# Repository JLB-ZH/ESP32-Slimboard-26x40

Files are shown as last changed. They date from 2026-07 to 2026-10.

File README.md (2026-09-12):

# ESP32-Slimboard-26x40  
Compact ESP32‑WROOM‑32 slim board (26×40 mm) for vertical or horizontal mounting, with a 10‑pin ZIF for programming and I²C/SPI interface.

## 🧩 The Board
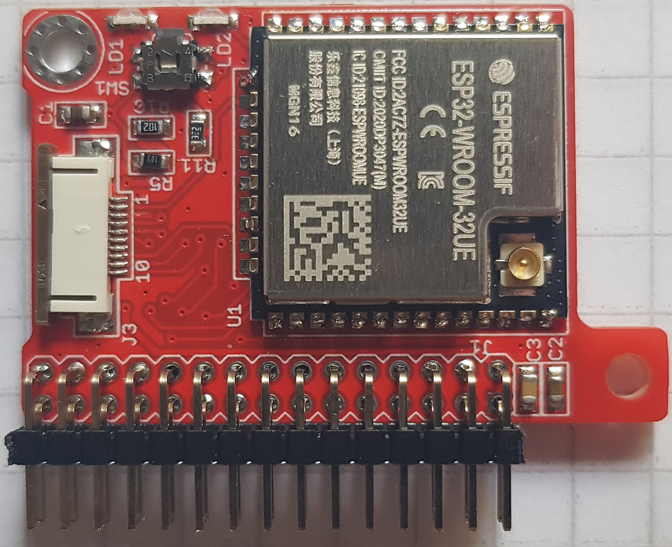
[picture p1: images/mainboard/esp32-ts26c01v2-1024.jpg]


The processor board is made arround the ESPRESSIF ESP32‑WROOM‑32UE with 16 MB of flash (or 32E if no external antenna needed).

USB interface and onboard 3.3V regulator are not provided, an external adapter (see [Tools](#-tools)) can be used for initial programming. OTA updates can be used afterwards.

The board features a 2×15 pin male connector with 2.0 mm pitch, allowing use on prototyping platforms or production boards.

It has been developed with Eagle Cad version 4.16, but Eagle 6 compatible files (XML format) are provided [here](hardware/), and can be easily imported into KICAD.

The mechanical and pinout specifications can apply to many different microcontroller or SOC, including BEKEN BK72xx series, REALTEK RTL8720, if no CANbus needed, just adapt the schematic and use the libraries available in JLB_processor.lbr.

## 📜 Specifications
- Small size: 26x40mm
- 2× holes for 2,5mm screews
- Soc module on-board: ESP32‑WROOM‑32‑E (or UE)
  - 240MHz
  - 16MB Flash
  - 520KB Sram
  - 448 KB Rom
  - CAN 2.0
  - Wifi, Bluetooth
  - many GPIOs
- Externally provided 3.3V power supply
- 1× 2×15×2.0 mm male connector
  - Straight version for horizontal mounting
  - Right‑angle version for vertical mounting  
- Reset button    
- 2× indicators
  - red LED on GPIO0  
  - green LED on GPIO2  
- 1× 1x10x0.5mm ZIF connector 
  - for Jtag or Uart programming (ESPPROG2 + adapter recommended)
  - for I²C or SPI expansion
## 🔌 Connectivity
### main connector
Pins in this table have been assigned to application-specific signals, but all GPIO can be reassigned to other functions by software if necessary.
Main connector
### Zif connector
Zif connector
## 🖼 Application examples and projects
<table>
  <tr>
    <td><strong>Linky interface</strong></td>
    <td><strong>Tank level Sensor interface</strong></td>
    <td><strong>Prototyping baseboard</strong></td>
  </tr>
  <tr>
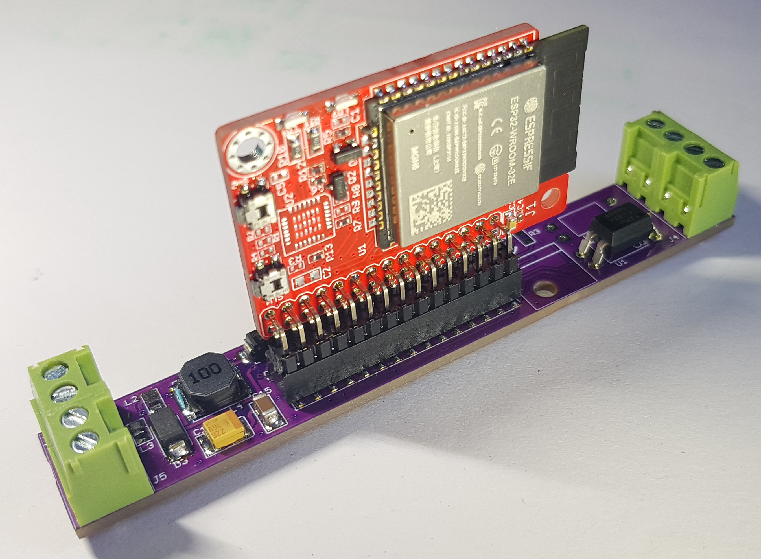
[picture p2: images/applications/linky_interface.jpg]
    <td></td>
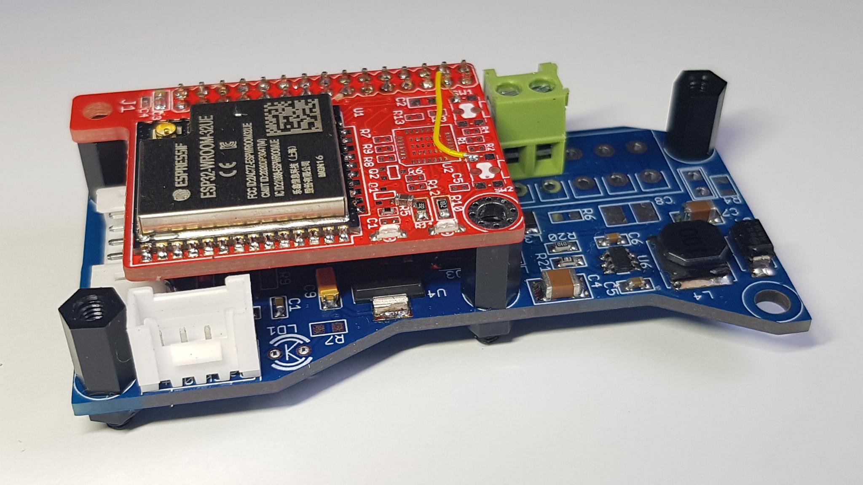
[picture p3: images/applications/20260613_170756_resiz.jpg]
    <td></td>
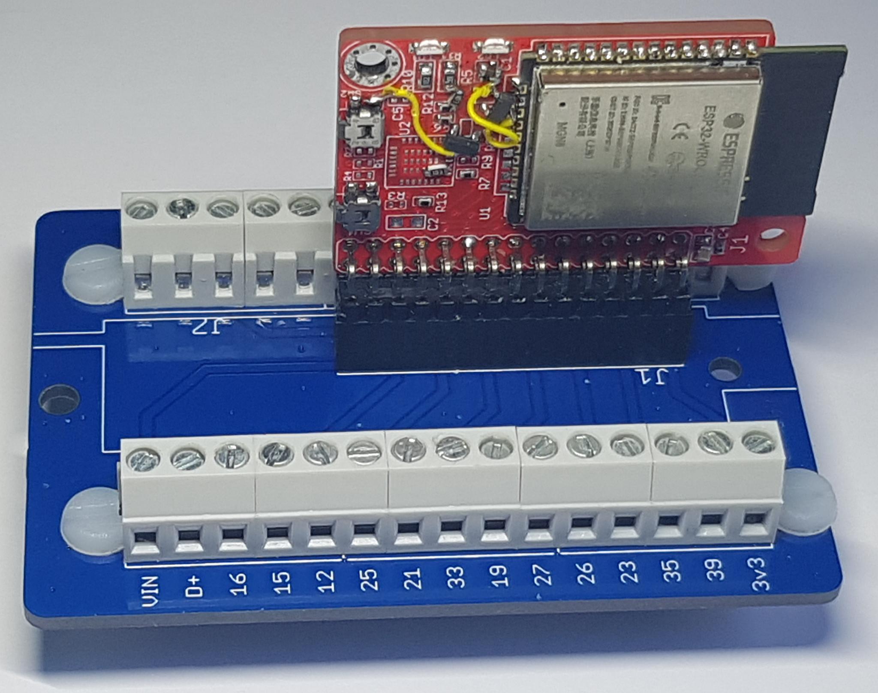
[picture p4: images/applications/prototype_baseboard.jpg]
    <td></td>
  </tr>
</table>

## 📐 Hardware design
Design and library files are provided [here](hardware/) in Eagle 6 format (xml files) that can easily be imported into KICAD.

## 🛠 Tools
|[Uart programming module](https://soldered.com/products/connect-programmer)|[ESPPROG-2 tool](https://docs.espressif.com/projects/esp-dev-kits/en/latest/other/esp-prog-2/user_guide.html)|ZIF programmer|Programming on socket|
|:---:|:---:|:---:|:---:|
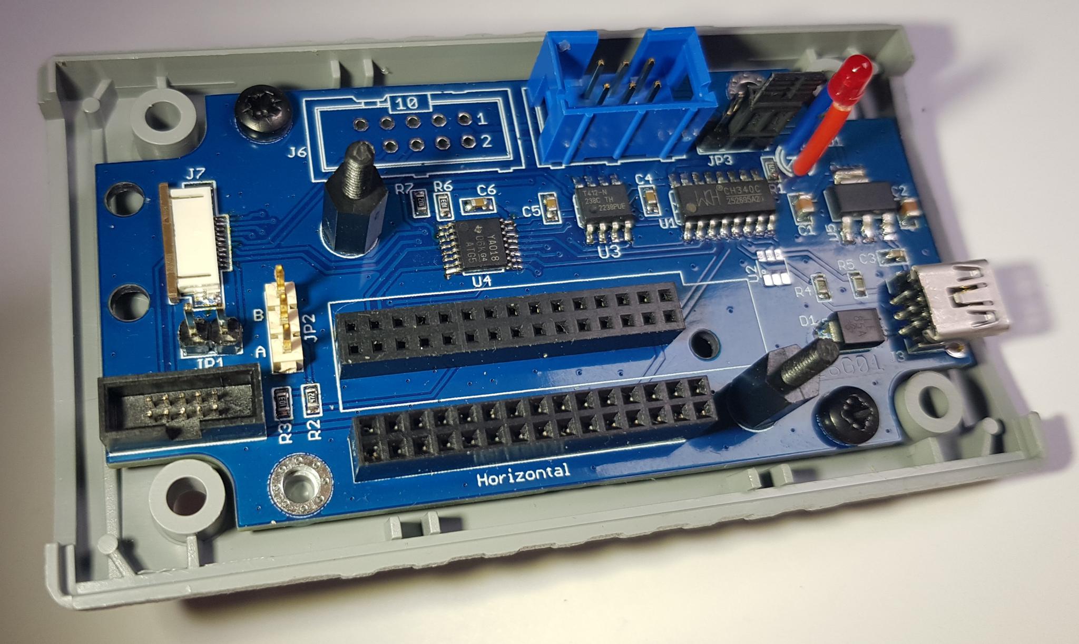
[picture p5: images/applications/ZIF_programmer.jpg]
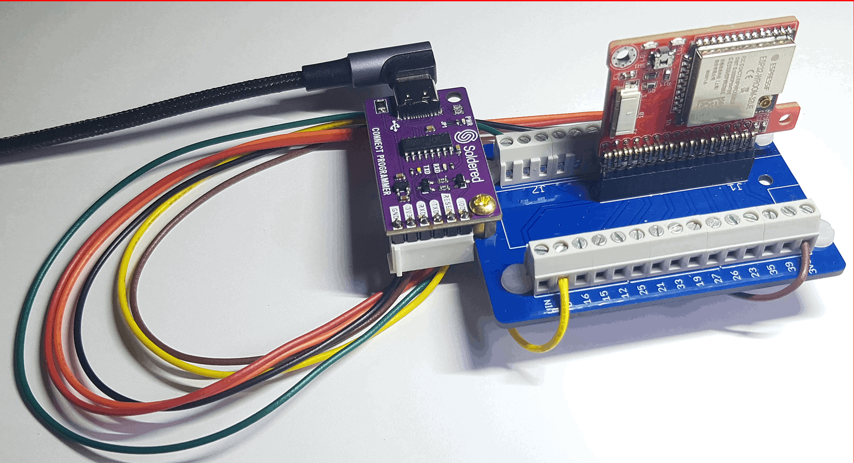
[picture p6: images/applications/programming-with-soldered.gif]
|||||

## 📑 Table of Contents
- [Processor Board](#-the-board)
- [Software examples](software/arduino/)
- [Hardware](hardware/)
- [Documents](documents/)

## 🛡 Licenses
- [Software](licenses/software/LICENSE-APACHE) : Apache-2.0
- [Hardware](licenses/hardware/LICENSE-CERN-OHL-S) : CERN-OHL-S v2

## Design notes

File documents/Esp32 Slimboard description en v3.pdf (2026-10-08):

## ESP32 Miniboard

## ESP32 processor for embedded applications

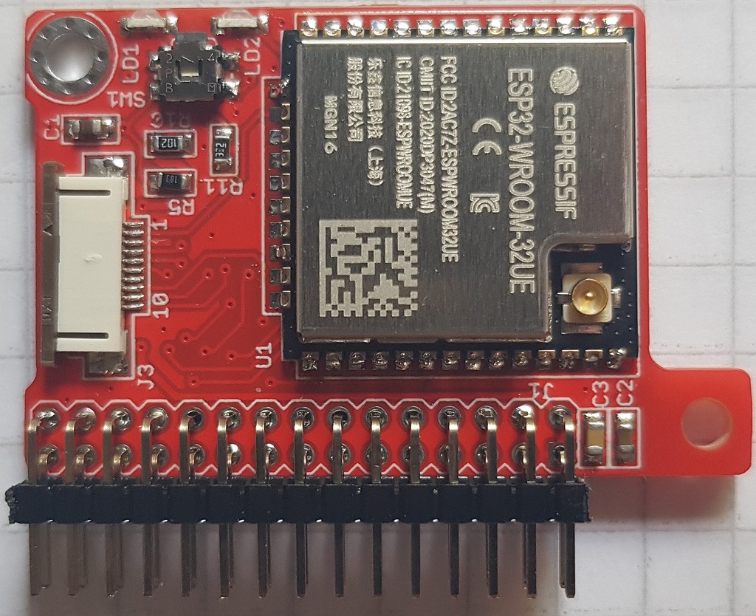
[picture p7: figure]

October 2026 – v0.1 | ESP32-SLIM-2640 | page 1

History

Document history
2026-08-12 v0.0
– initial version
2026-10-08 v0.1
– exchanged GPIO18-21 & GPIO19-25
– replaced schematic
– removed usb D+ & D- labels for pin 27-28 – added colored 2x15 connctor pinout table

Product description

the ESP32 slimboard
The product consists of a redesigned format of the usual ESP32 devkit, allowing the usage in custom application mainboards in vertical or horizontal position, and in as small as possible enclosures like DIN rail modules, waterproof cases, wall mounting boxes.

To achieve the dual position feature, a single double row (2x15) connector will be provided, either straight for horizontal mount, or right-angle for vertical.

Its size, 26x40mm, has also been reduced (smaller than a pocket matchbox)

Github repository
https://github.com/JLB-ZH/ESP32-Slimboard-26x40 (https://github.com/J85FR/ESP32-Slimboard-26x40)

The board
The board is fitted with an ESP32-WROOM-32UE (the E model can be used if no external antenna is needed) with 16MB of flash memory.

There is no USB interface nor 3.3V regulator on-board, since that feature is only used a very few times in the product life (an external adapter need to be used for programming the processor at first time, OTA can be used further)

It features a 2x15 pin male connector with a 2.0mm pitch, allowing its use on prototyping or production platform.

Two sideleds are mounted on the PCB.

Specifications :

– dimensions : 26x40x7mm
– Soc ESP32-WROOM32-E (or UE)
– external 3.3V power supply
– 1x 2x15x2.0mm male connector (Straight for horizontal or right-angle for vertical mounting)
– Reset button
– 2x LED indicators
– red LED on GPIO0, active LOW
– green LED on GPIO2, active HIGH
– 1x 10x0.5mm ZIF connector for Uart or Jtag programming and I²C/SPI expansions – Communication
– Wifi
– Bluetooth
– I²C
– Can
– Uart
– 1 Wire

Adapter boards are available for use on prototyping boards.

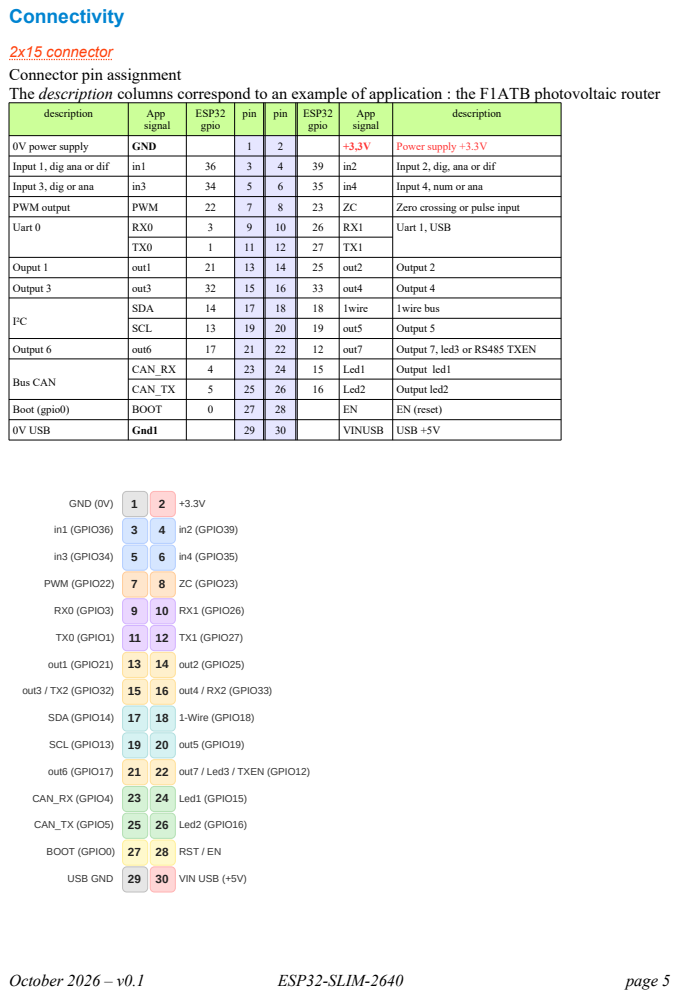
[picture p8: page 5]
Connectivity; GND (0V); in1 (GPIO36); 4 in2 (GPIO39); in3 (GPIO34); 6 in4 (GPIO35); PWM (GPIO22); 8 ZC (GPIO23); RX0 (GPIO3); 10 RX1 (GPIO26); TX0 (GPIO1); 11 12 TX1 (GPIO27); out1 (GPIO21); 13 14 out2 (GPIO25); out3 / TX2 (GPIO32); 15 16 out4 / RX2 (GPIO33); SDA (GPIO14); 17 18 1-Wire (GPIO18); SCL (GPIO13); 19 20 out5 (GPIO19); out6 (GPIO17); 21 22 out7 / Led3 / TXEN (GPIO12); CAN_RX (GPIO4); 23 24 Led1 (GPIO15); CAN_TX (GPIO5); 25 26 Led2 (GPIO16); USB GND; 29 30 VIN USB (+5V)

2x15 connector
Connector pin assignment
The description columns correspond to an example of application : the F1ATB photovoltaic router

description | App signal | ESP32 gpio | pin | pin | ESP32 gpio | App signal | description

0V power supply | GND | | 1 | 2 | | +3,3V | Power supply +3.3V
Input 1, dig ana or dif | in1 | 36 | 3 | 4 | 39 | in2 | Input 2, dig, ana or dif
Input 3, dig or ana | in3 | 34 | 5 | 6 | 35 | in4 | Input 4, num or ana
PWM output | PWM | 22 | 7 | 8 | 23 | ZC | Zero crossing or pulse input
Uart 0 | RX0 | 3 | 9 | 10 | 26 | RX1 | Uart 1, USB

Ouput 1 | out1 | 21 | 13 | 14 | 25 | out2 | Output 2
Output 3 | out3 | 32 | 15 | 16 | 33 | out4 | Output 4
I²C | SDA | 14 | 17 | 18 | 18 | 1wire | 1wire bus

SCL | 13 | 19 | 20 | 19 | out5 | Output 5

Output 6 | out6 | 17 | 21 | 22 | 12 | out7 | Output 7, led3 or RS485 TXEN
Bus CAN | CAN_RX | 4 | 23 | 24 | 15 | Led1 | Output led1

CAN_TX | 5 | 25 | 26 | 16 | Led2 | Output led2

Boot (gpio0) | BOOT | 0 | 27 | 28 | | EN | EN (reset)
0V USB | Gnd1 | | 29 | 30 | | VINUSB | USB +5V

BOOT (GPIO0) 27 28 RST / EN

Zif connector
The ZIF connector allows :
– programming the ESP32 by Jtag with the ESPPROG2 board + additional adapter board – programming the ESP32 by Uart autoprog mode with the ESPPROG2 board + additional adapter board
– connecting any I²C péripheral custom board or display directly to the ESP32 board
– Adding an external Sdcard or SPI memory
Pin | GPIO | Fonctions
1 | VDD | +3,3V
2 | GPIO13 | I²C CLK / JTAG TCK / HSPI D
3 | GND | GND
4 | GPIO14 | I²C DATA / JTAG TMS / HSPI CLK
5 | GPIO15 | JTAG TDO / HSPI CS0
6 | GPIO12 | JTAG TDI / HSPI Q
7 | EN | Reset / Enable
8 | GPIO0 | Boot mode (IO0)
9 | GPIO3 | UART0 RX
10 | GPIO1 | UART0 TX

Schematic

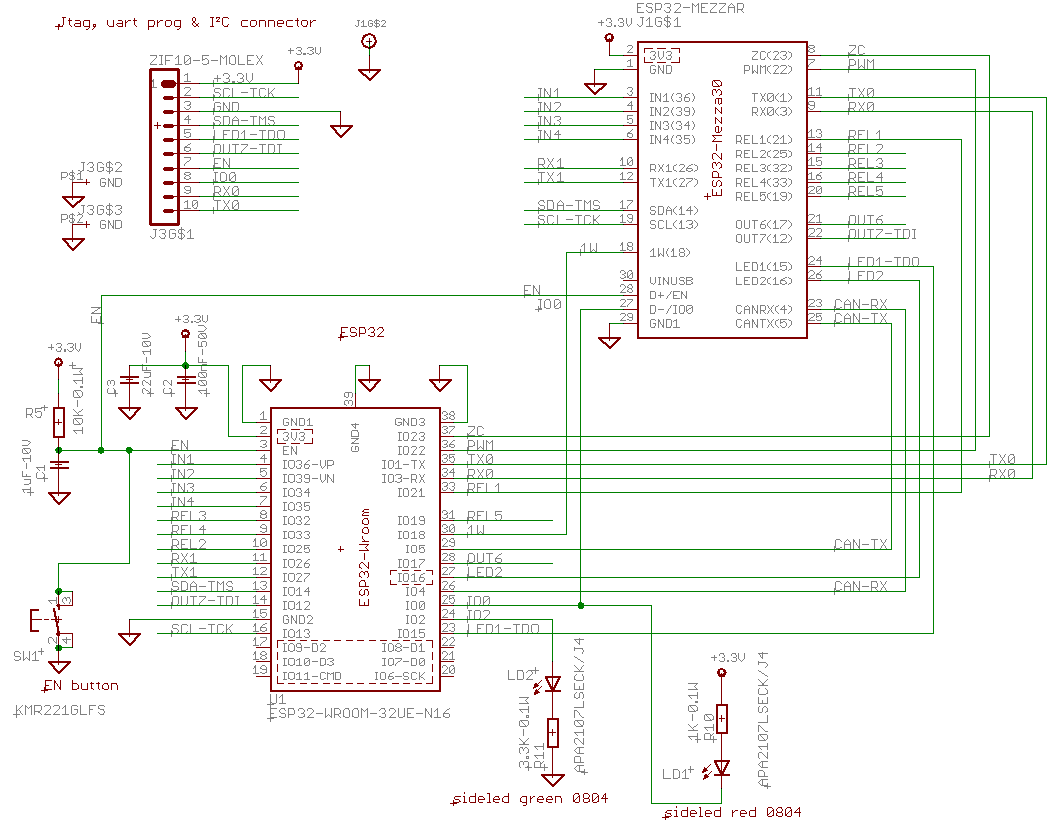
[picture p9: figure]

Bom
Components list
Part Value | Device | Package | Description
C1 | 1uF-10V | CAP-0603-L | C0603
C2 | 100nF-50V | CAP-0603-L | C0603
C3 | 22uF-10V | CAP-0603-L | C0603
J1 | ESP32-MEZZAR | ESP32-MEZZAR | ESP32-MEZZA25-R | Module ESP32 40mm 2x15x2.0mm vertical, horizontal, normal, reverse
J3 | ZIF10-5-MOLEX | ZIF10-5-MOLEXSTD | 52746-1071-J
LD1 | APA2107LSECK/J4 | SIDELED_0805 | SIDELED_0805 | Sideled 0805 kingbright APA2107
LD2 | APA2107LSECK/J4 | SIDELED_0805 | SIDELED_0805 | Sideled 0805 kingbright APA2107
R5 | 10K-0.1W | R-EU_R0603-S | 0603 | RESISTOR, European symbol
R10 | 1K-0.1W | R-EU_R0603-S | 0603 | RESISTOR, European symbol
R11 | 3.3K-0.1W | R-EU_R0603-S | 0603 | RESISTOR, European symbol
SW1 KMR221GLFS | SW-TACT-NOGNDSIDE | SW-KMS-HOLE-NOGND | Tactile button C&K KMR
U1 | ESP32-WROOM-32UE-N16 ESP32-WROOM-UE | ESP32-WROOM-32UE | SOC ESP32-Wroom E antene pcb

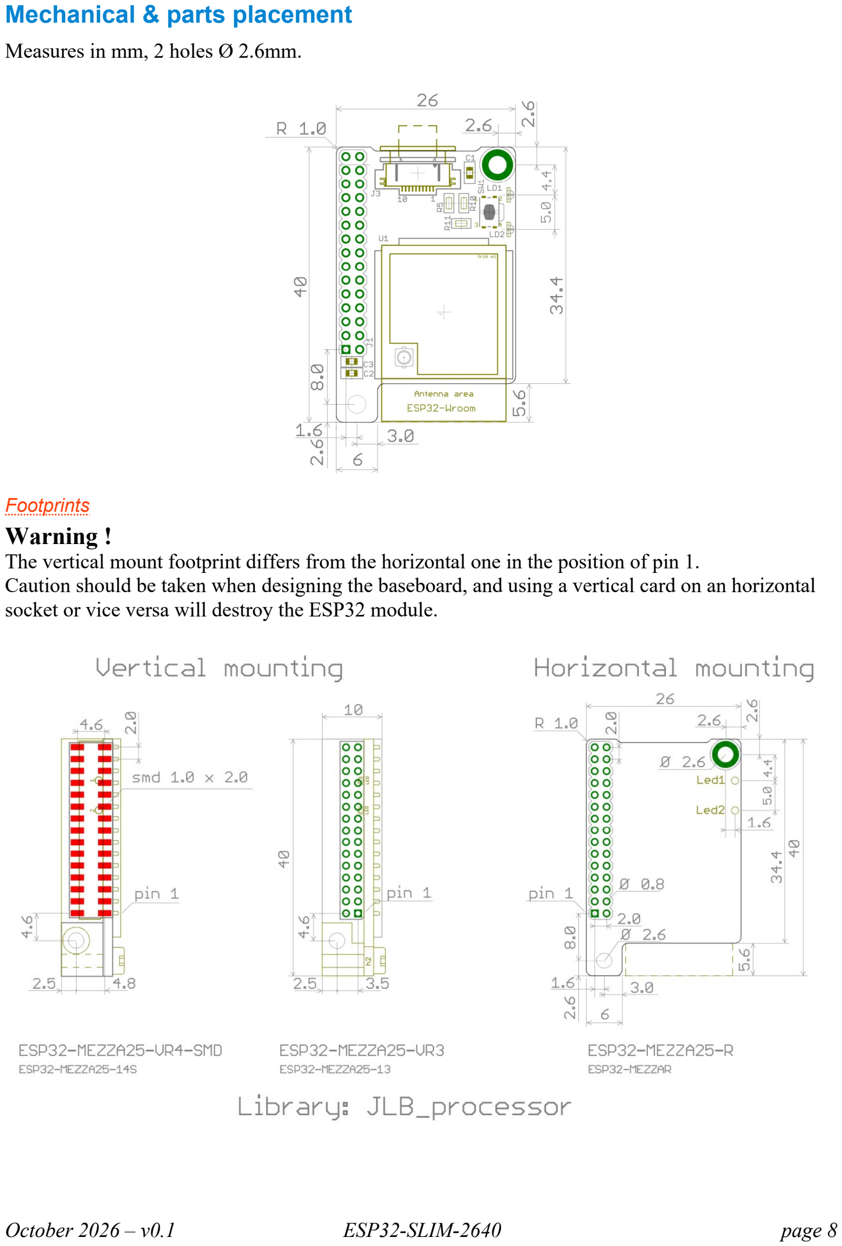
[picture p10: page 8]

Mechanical & parts placement Measures in mm, 2 holes Ø 2.6mm.

Footprints
Warning !
The vertical mount footprint differs from the horizontal one in the position of pin 1.
Caution should be taken when designing the baseboard, and using a vertical card on an horizontal socket or vice versa will destroy the ESP32 module.

Software

Onboard Leds
Note :
the on-board red LED is connected to GPIO0, is activated with a LOW level
the on-board green LED is connected to GPIO2, is activated with a HIGH level

When using Arduino IDE, GPIO2 is considered as the ESP32 devkit onboard LED, and is driven by the librairies to reflect the Wifi Status.
In order to disable this function and take control of GPIO2 for your application usage, or switch off this LED, it is necessary to add this piece of code at the beginning of the setup() function, after Wifi initialisation call :
#define | Red_led | 0 | // led 1 on ESP32 wroom board

#define | Green_led | 2 | // led 2 on ESP32 wroom board

void | setup() | {
Serial.begin(115200);
WiFi.begin(ssid, password);
// reinit gpio2 pin
// |
pinMode(Green_led, OUTPUT); GreenLedOFF();

Various Applications

OpenPLC
An opensource PLC, supported through the following website https://autonomylogic.com/

It is possible to add custom functions into the PLC program.

It can easily be interfaced with HomeAssistant through the Modbus integration

F1ATB Photovoltaic router
Solar Energy Router to manage overproduction (DIY) – F1ATB (https://f1atb.fr/home-automation/esp32/diy-solar-energy-router-to-manage-overproduction/)

A system that can use the available power from solar panel to drive any resistive load, leaving priority to the other installation equipments.

CAN bus gateway
Another interesting project is the HAPCAN one, for lighting management over CANbus, where any device can interact with any of the other devices connected to the bus, even itself.

The ESP32 board can be used as a CAN gateway, or as a button interface, if installed inside a wall

mounting box
Enclosures
The board can be installed on a custom baseboard, either in vertical position, for instance in slim Din rail enclosures, or even horizontally position if space enough.
One module Din rail baseboard | Custom sensor baseboard

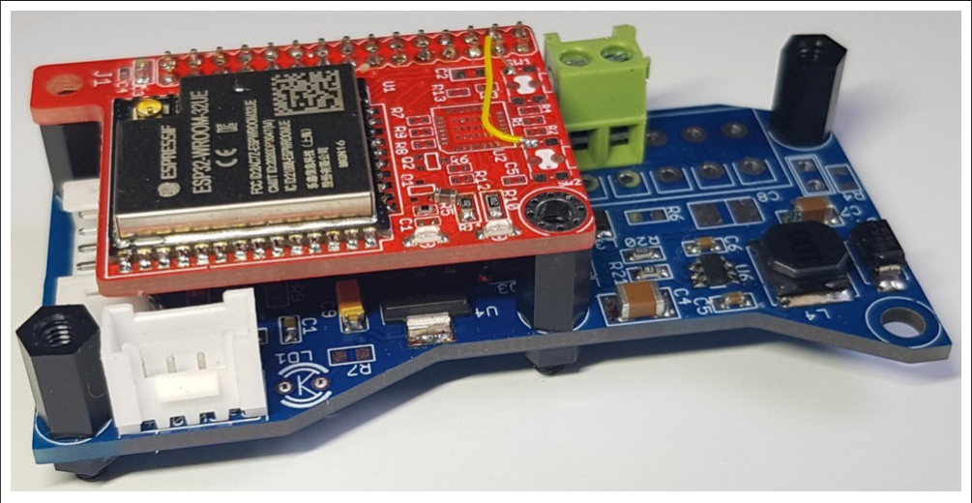
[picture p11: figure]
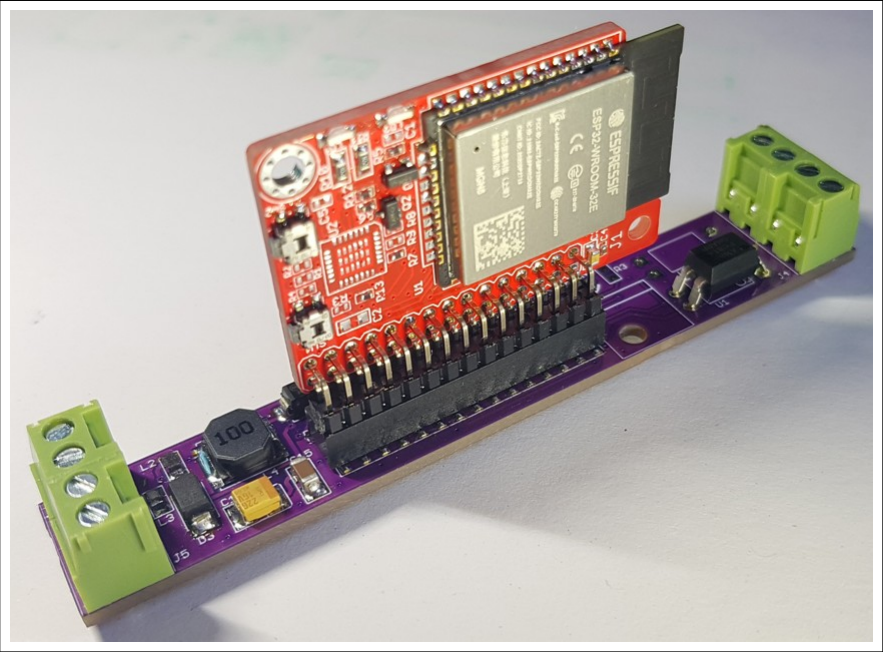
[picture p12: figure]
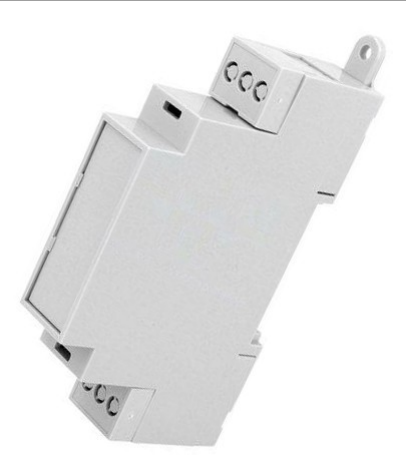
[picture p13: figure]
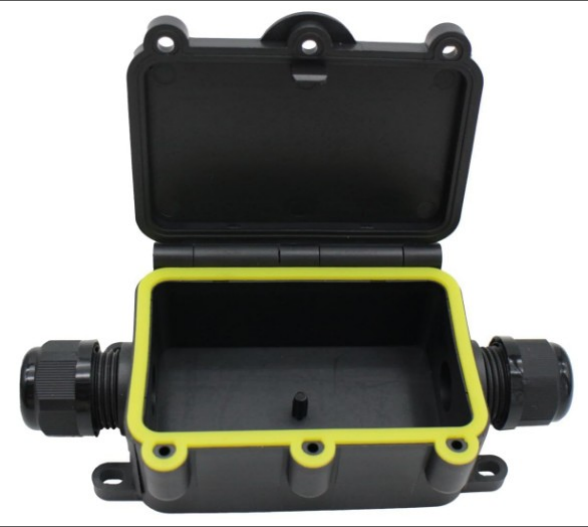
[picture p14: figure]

Programming
Software can be programmed into the ESP32 card by several ways.

SOLDERED Connect card

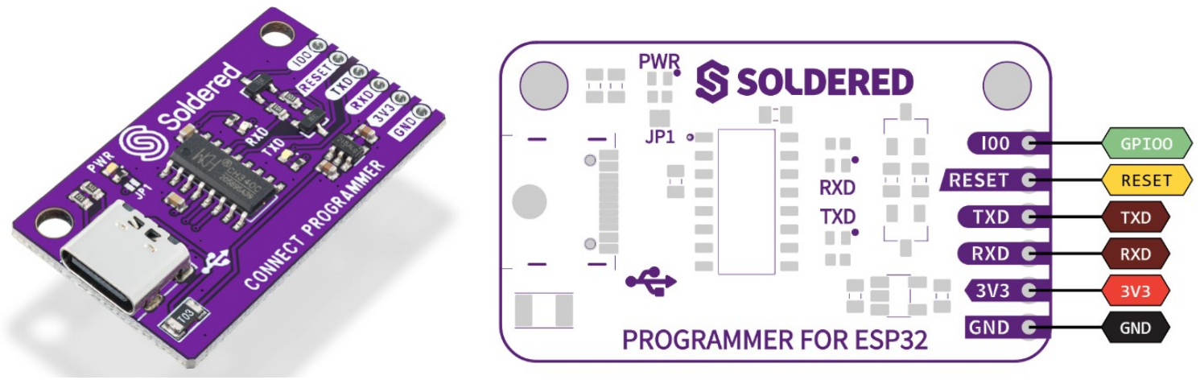
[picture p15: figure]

this small and low cost card with USB-C type connector uses a CH340C chip, and generates the IO0 and EN signals necessary to reset and boot the ESP32.

A simple 1x6 pin header must be provided on the base board, and a 5 or 6 wires cable provided between the programming card and the baseboard

pin | Prog card | Esp32 card | 2x15 connector | ESP32 GPIO | description
1 | Gnd | Gnd | 1 | | 0V power ground
2 | +3.3V | +3.3V | 2 | | Do not connect if 3.3V to ESP32 is provided by the baseboard
3 | RXD | TX0 | 11 | GPIO1 | RXD of CH340, TX0 of ESP32
4 | TXD | RX0 | 9 | GPIO3 | TXD of CH340, RX0 of ESP32
5 | RESET | EN | 28 | | EN
6 | GPIO0 | IO0 | 27 | GPIO0 | IO0

ESPprog2 card
an Espressif esp32 based programming card with a Jtag interface and an Uart programming interface.

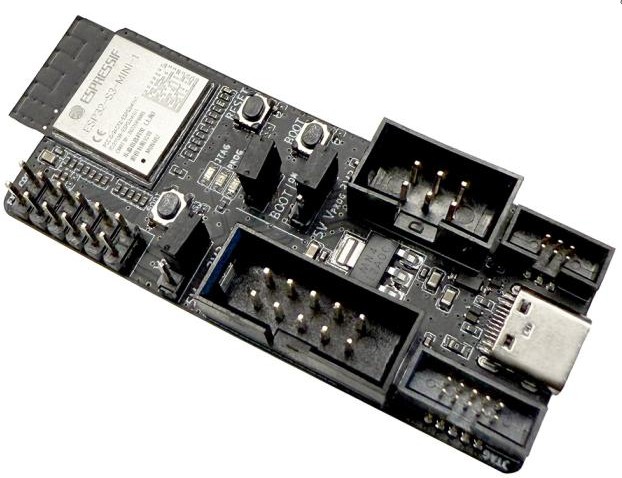
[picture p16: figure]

Zif Adapter card
this multifunction custom card provides the Zif connector and can program the ESP32 card in either vertical or horizontal position, and be interfaced with the ESPPROG2 card or SOLDERED Connect card.
It also can be directly connected to an USB port for programming (onboard CH340-C)
An option jumper can be installed to provide +3.3V power to the Zif connector.

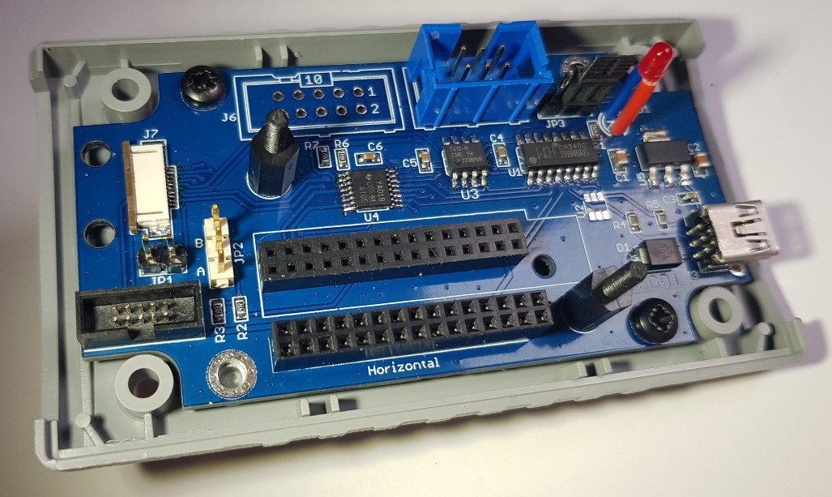
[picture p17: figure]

CAPUF card
ESP32 Programmer V1: ESP32 Programmer (https://capuf.in/esp32-programmer-board/)
a 5 or 6 wires custom cable should be made as described above. This card uses a CP2102 chip for Usb to Uart conversion.

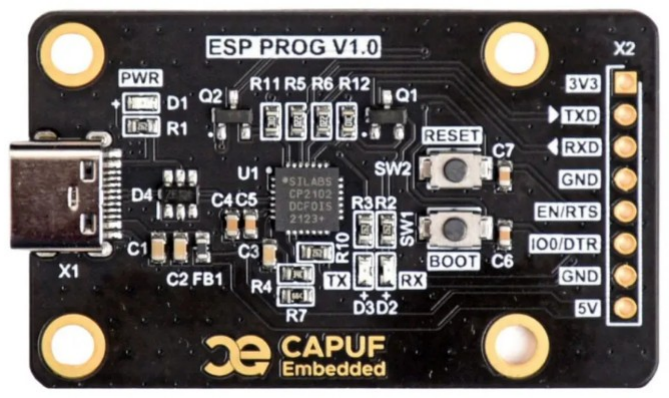
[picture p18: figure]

Custom baseboard with connection blocks
the following custom programming platform uses the SOLDERED 'Connect' card (vertical mode only)

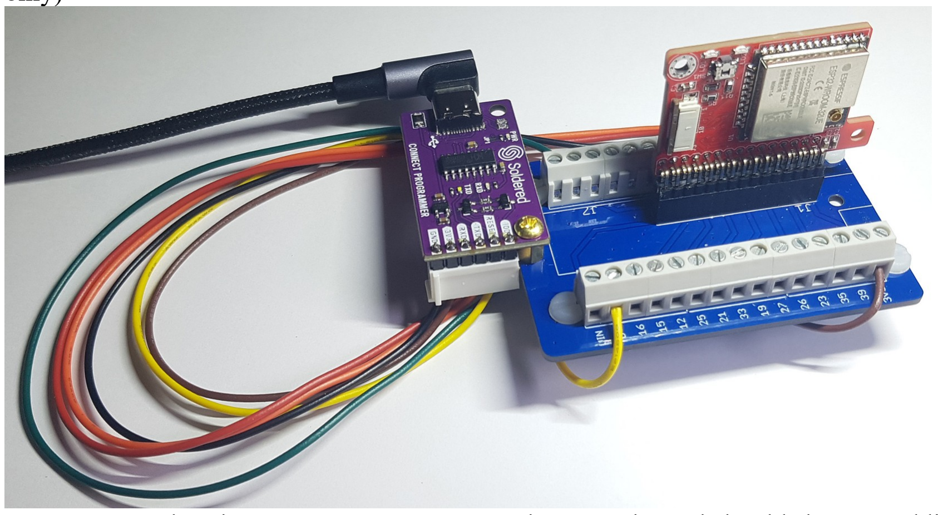
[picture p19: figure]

once connected to the computer on USB port, the control panel should show an additional COM port device : COM5

description | App signal | ESP32 gpio | pin | pin | ESP32 gpio | App signal | description
0V power supply | GND | | 1 | 2 | | +3,3V | Power supply +3.3V
| | | 3 | 4
| | | 5 | 6
| | | 7 | 8
Uart 0 | RX0 | 3 | 9 | 10
| TX0 | 1 | 11 | 12
| | | 13 | 14
| | | 15 | 16
| | | 17 | 18
| | | 19 | 20
| | | 21 | 22
| | | 23 | 24
| | | 25 | 26
Boot (gpio0) | BOOT | 0 | 27 | 28 | | EN | EN (reset)
| | | 29 | 30

a simple software example

// ===================================================================== // a simple example that makes the 2 onboard leds blink asynchronously // =====================================================================
#include | "freertos/FreeRTOS.h"

#include | "freertos/task.h"

// on-board LEDs
#define | LED_red | 0 | // GPIO0, active low

#define | LED_green | 2 | // GPIO2, active high

// red LED blinking task
//----------------------------
void | BlinkRedLedTask(void | *pvParameters) | {
const | TickType_t | xDelay = | pdMS_TO_TICKS(500); | // 500ms delay
while | (1) | {
ledON(LED_red);
vTaskDelay(xDelay); // Delay for 500ms
ledOFF(LED_red);
vTaskDelay(xDelay); // Delay for 500ms }
}
// initialisation
//----------------
void | setup() | {
// put your setup code here, to run once:
pinMode(LED_green, OUTPUT); // this also disable the GPIO2 from beeing the Wifi status led ledOFF(LED_green);

pinMode(LED_red, OUTPUT);
ledOFF(LED_red);

Serial.begin(115200);
Serial.println("Start blinky task");
xTaskCreate(BlinkRedLedTask, | "blink_led_red", | 2048, | NULL, | 1, | NULL);
}

// main loop
//-----------
void | loop() | {
ledON(LED_green);
delay(100);
ledOFF(LED_green);
delay(900);
}

// functions
//------------

void | ledON(int | led) | {
if | (led == LED_green)
{
Serial.println("LED_green ON"); digitalWrite(led, HIGH);
}
else
if (led == LED_red)
{
digitalWrite(led, LOW);
}
}
void | ledOFF(int | led) | {
if | (led == LED_green)
{
Serial.println("LED_green OFF"); digitalWrite(led, LOW);
}
else
if (led == LED_red)
{
digitalWrite(led, HIGH);
}
}

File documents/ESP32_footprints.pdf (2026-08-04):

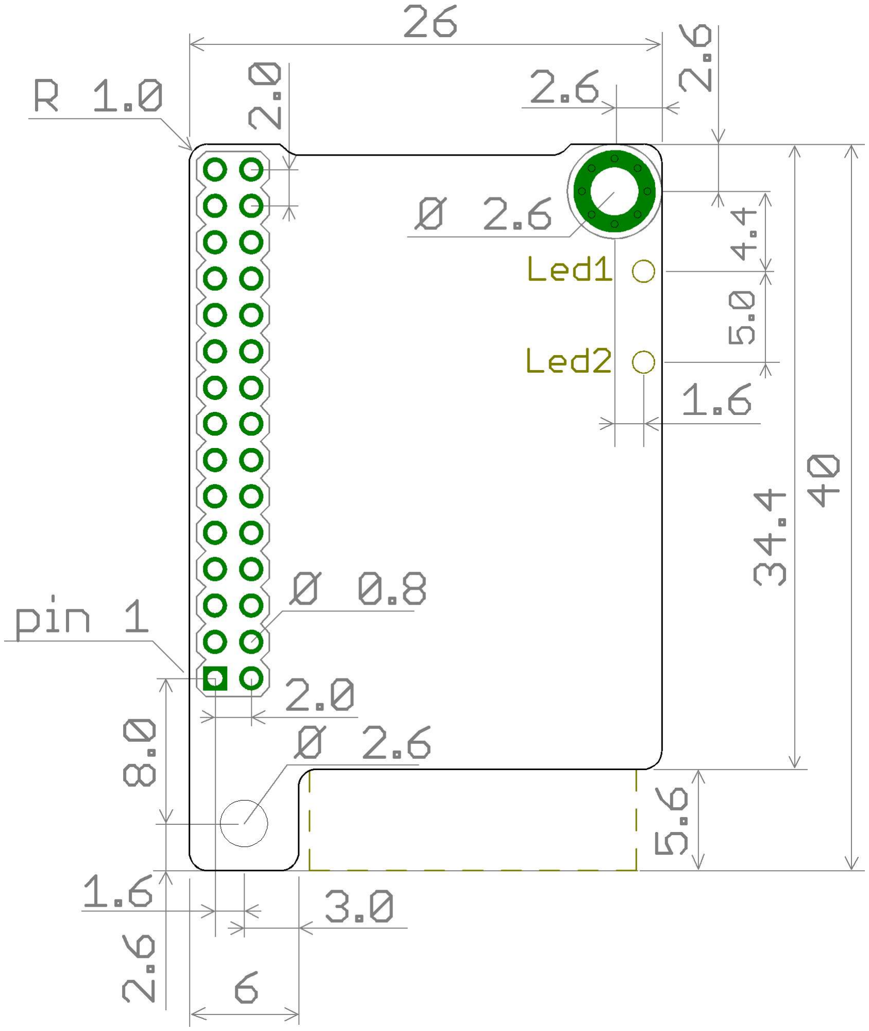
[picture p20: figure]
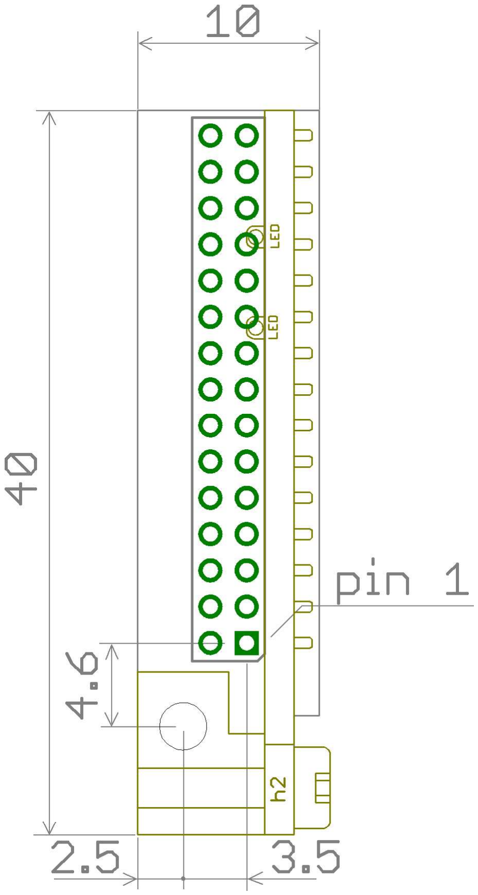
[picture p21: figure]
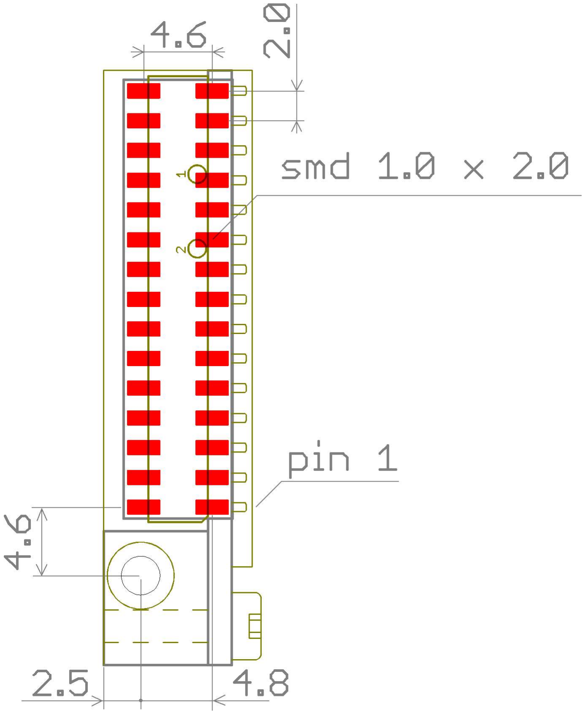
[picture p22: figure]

04/08/2026 12:51:32 f=1.44 E:\Data\Etudes\@_EagleProjects\ESP32_footprints\ESP32_footprints.brd

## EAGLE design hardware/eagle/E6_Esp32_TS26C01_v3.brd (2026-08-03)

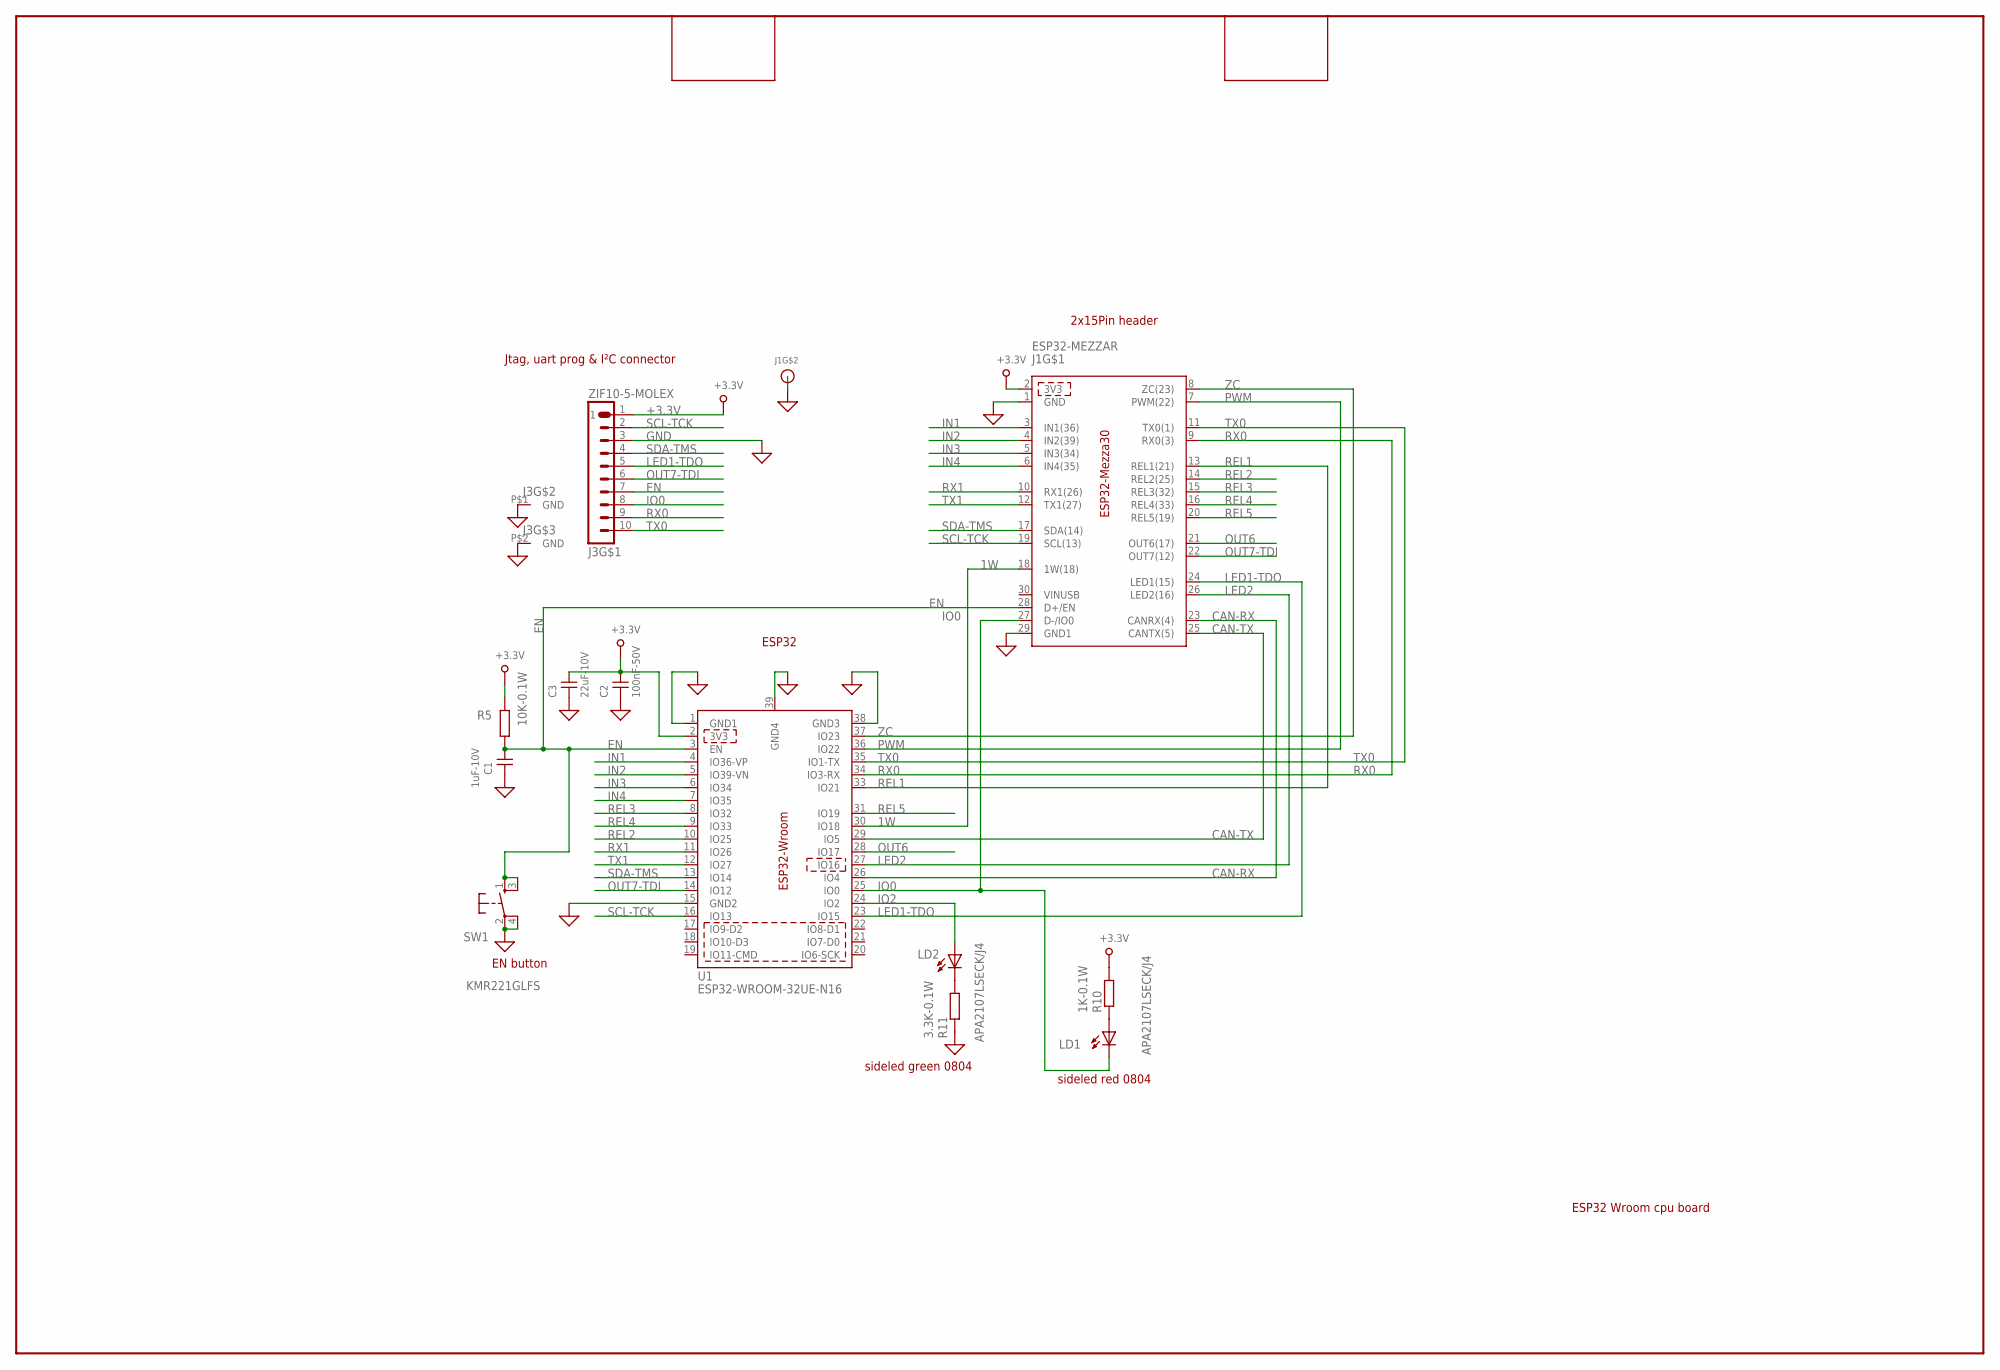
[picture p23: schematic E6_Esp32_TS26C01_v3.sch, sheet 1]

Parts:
C1: 1uF-10V; C0603
C2: 100nF-50V; C0603
C3: 22uF-10V; C0603
J1: ESP32-MEZZAR; ESP32-MEZZA25-R
J3: ZIF10-5-MOLEX; 52746-1071-J
LD1, LD2: APA2107LSECK/J4; SIDELED_0805
R5: 10K-0.1W; 0603
R10: 1K-0.1W; 0603
R11: 3.3K-0.1W; 0603
SW1: KMR221GLFS; SW-KMS-HOLE-NOGND
U1: ESP32-WROOM-32UE-N16; ESP32-WROOM-32UE

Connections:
1W: J1.18 (1W(18)), U1.30 (IO18)
+3.3V: C2.2, C3.2, J1.2 (3V3), J3.1, R5.1, R10.1, U1.2 (3V3)
CAN-RX: J1.23 (CANRX(4)), U1.26 (IO4)
CAN-TX: J1.25 (CANTX(5)), U1.29 (IO5)
EN: C1.2, J1.28 (D+/EN), J3.7, R5.2, SW1.1 (S), SW1.3 (S), U1.3 (EN)
GND: C1.1, C2.1, C3.1, J1.1 (GND), J1.29 (GND1), J1.31, J3.3, J3.P$1 (GND), J3.P$2 (GND), J3.P$3 (GND), J3.P$5 (GND), R11.2, SW1.2, SW1.4, U1.1 (GND1), U1.15 (GND2), U1.38 (GND3), U1.39 (GND4)
IN1: J1.3 (IN1(36)), U1.4 (IO36-VP)
IN2: J1.4 (IN2(39)), U1.5 (IO39-VN)
IN3: J1.5 (IN3(34)), U1.6 (IO34)
IN4: J1.6 (IN4(35)), U1.7 (IO35)
IO0: J1.27 (D-/IO0), J3.8, LD1.C, U1.25 (IO0)
IO2: LD2.A, U1.24 (IO2)
LED1-TDO: J1.24 (LED1(15)), J3.5, U1.23 (IO15)
LED2: J1.26 (LED2(16)), U1.27 (IO16)
unnamed: LD1.A, R10.2
unnamed: LD2.C, R11.1
OUT6: J1.21 (OUT6(17)), U1.28 (IO17)
OUT7-TDI: J1.22 (OUT7(12)), J3.6, U1.14 (IO12)
PWM: J1.7 (PWM(22)), U1.36 (IO22)
REL1: J1.13 (REL1(21)), U1.33 (IO21)
REL2: J1.14 (REL2(25)), U1.10 (IO25)
REL3: J1.15 (REL3(32)), U1.8 (IO32)
REL4: J1.16 (REL4(33)), U1.9 (IO33)
REL5: J1.20 (REL5(19)), U1.31 (IO19)
RX0: J1.9 (RX0(3)), J3.9, U1.34 (IO3-RX)
RX1: J1.10 (RX1(26)), U1.11 (IO26)
SCL-TCK: J1.19 (SCL(13)), J3.2, U1.16 (IO13)
SDA-TMS: J1.17 (SDA(14)), J3.4, U1.13 (IO14)
TX0: J1.11 (TX0(1)), J3.10, U1.35 (IO1-TX)
TX1: J1.12 (TX1(27)), U1.12 (IO27)
ZC: J1.8 (ZC(23)), U1.37 (IO23)

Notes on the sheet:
ESP32 Wroom cpu board
ESP32
2x15Pin header
EN button
sideled red 0804
sideled green 0804
Jtag, uart prog & I²C connector

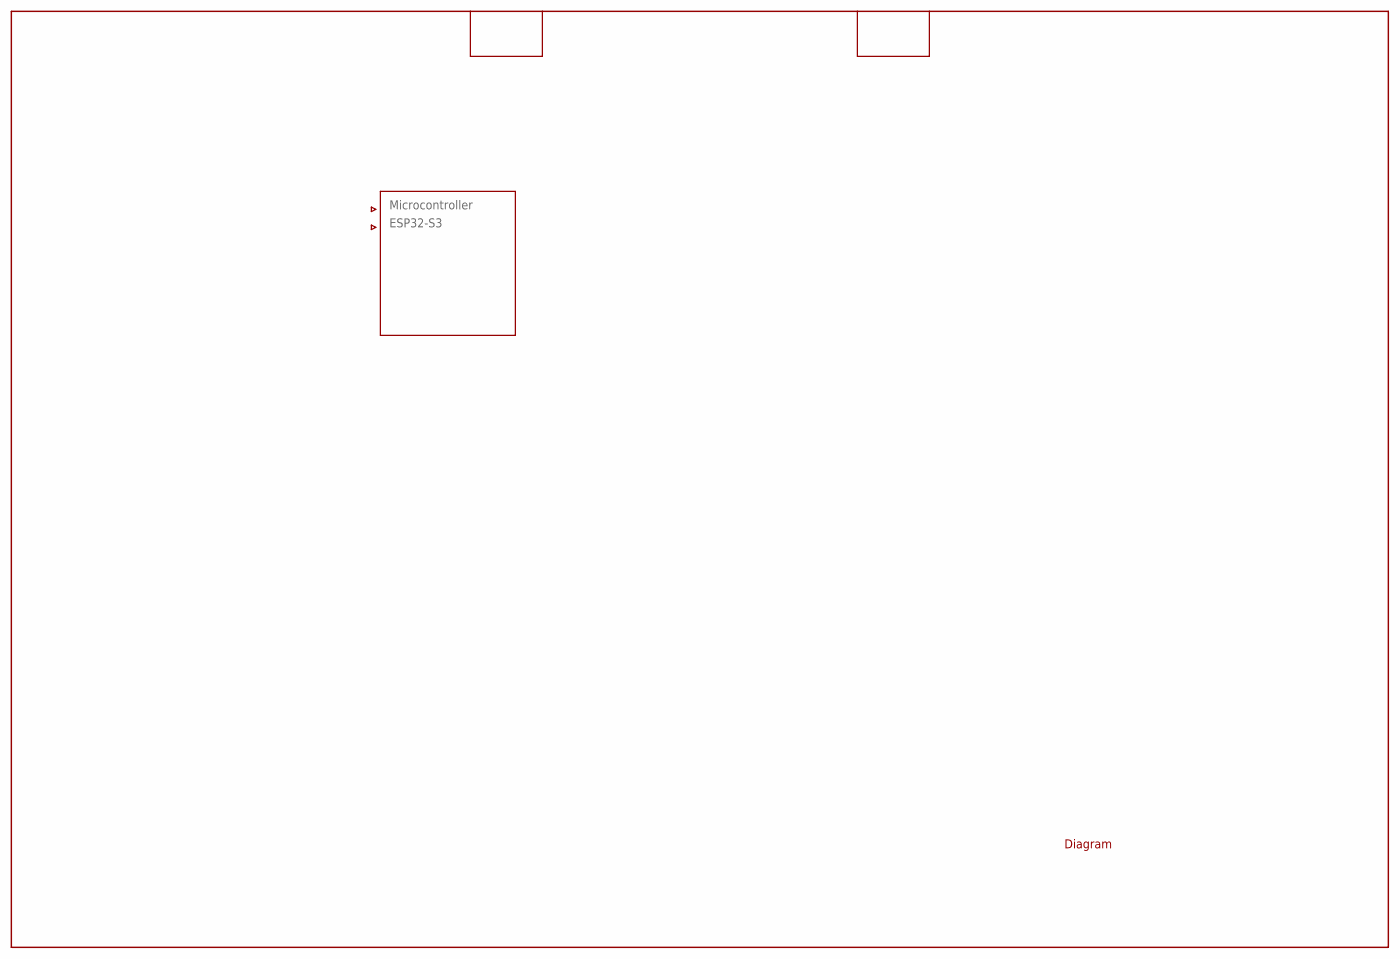
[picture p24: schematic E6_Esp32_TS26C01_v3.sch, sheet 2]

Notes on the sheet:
Diagram
Microcontroller
ESP32-S3

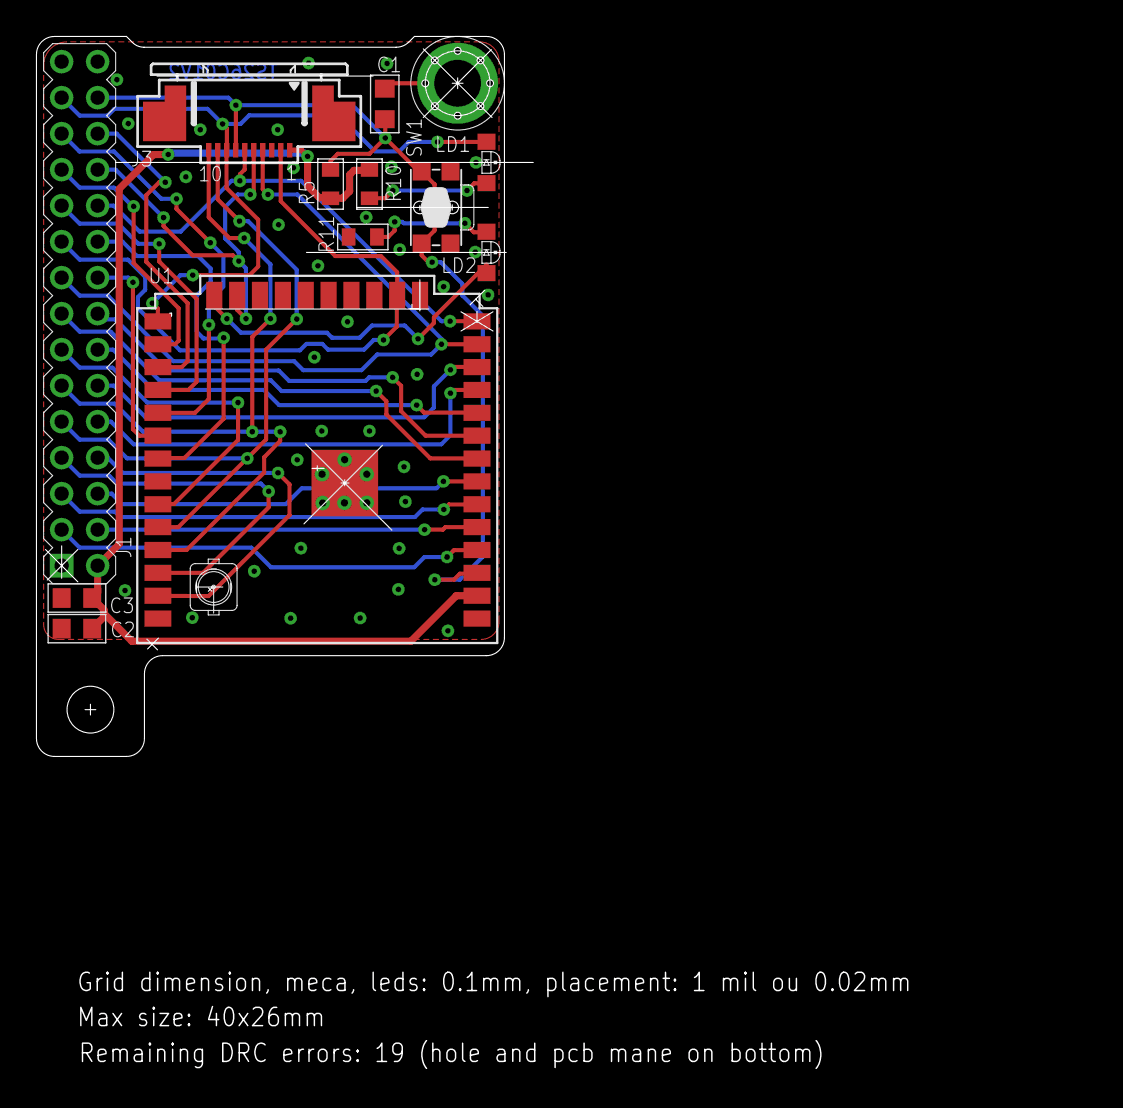
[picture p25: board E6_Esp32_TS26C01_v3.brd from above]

Board: 2 copper layers, 27.6 x 40.0 mm, 12 parts (0 on the bottom side), 31 nets.

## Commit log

2026-08-03 Rename programming with Soldered.jpg to programming-with-Soldered.jpg
2026-08-03 Change 'Prototyping baseboard' to 'Programming on socket'
    Updated the description of the prototyping baseboard in the tools section.
2026-08-04 Rename programming with soldered.gif to programming-with-soldered.gif
2026-08-05 Refine description of ESP32-Slimboard-26x40
2026-08-05 Update description of ESP32-Slimboard
2026-08-05 Update README with microcontroller compatibility details
    Added information about compatibility with different microcontrollers and schematic changes.
2026-08-05 Update GPIO pin assignment description in README
    Clarified the description of GPIO pin assignments.
2026-10-08 Delete images/others/pinout-2x15-color.svg
    pin assignments errors for gpio18,21,19,25, replacing file.
2026-10-08 correction of device ESP32-Mezza30
    correction for gpio 18,19,21,25 mismatches
2026-10-08 correction of sch for gpio 18,19,21,25
    no impact on Brd
    [E6_Esp32_TS26C01_v3.brd]
2026-10-08 correction for gpio 18,19,21,25
    no impact on brd
    [E6_Esp32_TS26C01_v3.sch]
2026-10-08 Delete hardware/eagle/E6_Esp32_TS26C01_v2.brd
    replaced by V3
    [E6_Esp32_TS26C01_v2.brd]
2026-10-08 Delete hardware/eagle/E6_Esp32_TS26C01_v2.sch
    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
    [E6_Esp32_TS26C01_v2.sch]
2026-10-08 Delete documents/Esp32 Slimboard description en.pdf
    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
